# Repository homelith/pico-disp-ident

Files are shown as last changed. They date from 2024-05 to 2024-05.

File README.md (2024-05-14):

# pico-disp-ident

## これは何？

- RP2040 搭載ボードと PicoDVI (https://github.com/Wren6991/PicoDVI) を使って、DVI ディスプレイに番号入りのテストパターン表示をさせるツールです。
- PicoDVI の feat/x8scale ブランチ (https://github.com/homelith/PicoDVI/tree/feat/x8scale) 版を用いることで、80x60 画像を VGA 640x480 ディスプレイに引き延ばして表示します。

## ハードウェア構築

- 記載中

## ソフトウェアビルド

- 環境準備
  + Linux ベースの OS 各種上でコンパイル可能と想定 (x86_64 ネイティブの ubuntu 22.04 LTS と WSL2 上の ubuntu 22.04 LTS で試験済)
  + パッケージインストール : `sudo apt install git gcc make cmake gcc-arm-none-eabi libnewlib-arm-none-eabi build-essential golang`

- uf2 バイナリをコンパイルする手順
  + 下記手順でコンパイル後、`sw/build/app/pico-disp-ident.uf2` が得られます

```
$ git clone --recursive git@github.com:homelith/pico-disp-ident.git
$ cd pico-disp-ident/sw
$ make
```

## デバイスを動作させる手順

- Raspberry Pi Pico への uf2 ファイルダウンロード
  + BOOTSEL ボタンを押しながら Raspi Pico の電源を投入することで、USB ポートがマスストレージデバイスとして認識されます
  + `pico-disp-ident.uf2` ファイルを該当ストレージの直下に置くことで書き込みとセルフリセットが行われます

- ボタンを押下すると表示画像と対応する 7seg の表示番号が切り替わります

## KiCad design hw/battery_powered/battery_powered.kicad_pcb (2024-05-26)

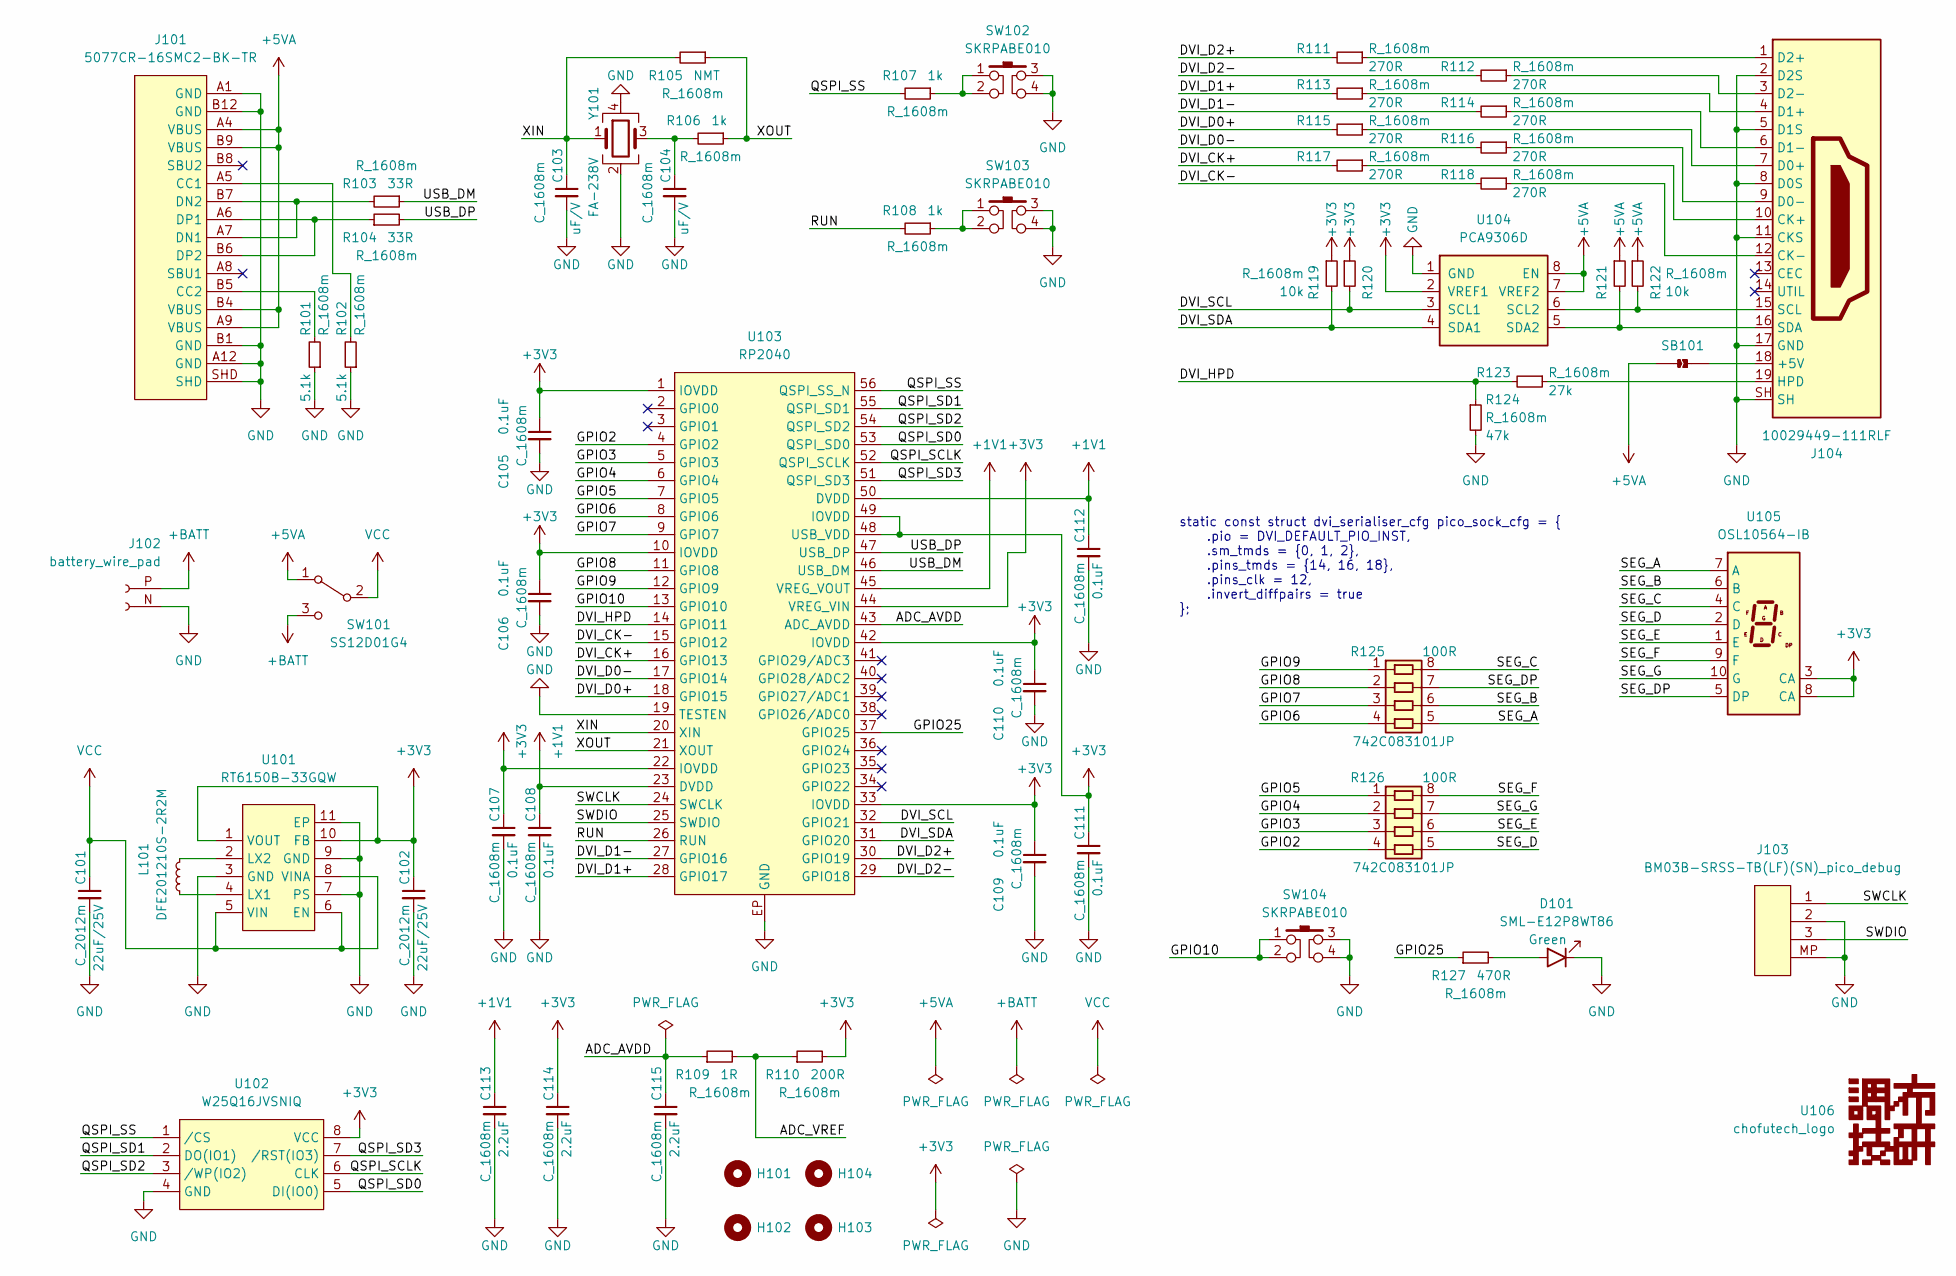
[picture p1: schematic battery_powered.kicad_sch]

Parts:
C101, C102: C_2012m
C103, C104, C105, C106, C107, C108, C109, C110, C111, C112, C113, C114, C115: C_1608m
D101: SML-E12P8WT86
H101, H102, H103, H104: MountingHole_2.2mm_M2; MountingHole_3.2mm_M3
J101: 5077CR-16SMC2-BK-TR; 5077CR-16SMC2-BK-TR_hand
J102: battery_wire_pad
J103: BM03B-SRSS-TB(LF)(SN)_pico_debug; BM03B-SRSS-TB(LF)(SN)_hand
J104: 10029449-111RLF; 10029449-111RLF_hand
L101: DFE201210S-2R2M
R101, R102, R103, R104, R105, R106, R107, R108, R109, R110, R111, R112, R113, R114, R115, R116, R117, R118, R119, R120, R121, R122, R123, R124, R127: R_1608m
R125, R126: 742C083101JP
SB101: jumper_2pole_solder
SW101: SS12D01G4
SW102, SW103, SW104: SKRPABE010; SKRPABE010_hand
U101: RT6150B-33GQW
U102: W25Q16JVSNIQ
U103: RP2040
U104: PCA9306D
U105: OSL10564-IB
U106: chofutech_logo; chofutech_logo_6.6mm
Y101: FA-238V

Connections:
+1V1: C108.1, C112.1, C113.1, U103.23 (DVDD), U103.45 (VREG_VOUT), U103.50 (DVDD)
+3V3: C102.1, C105.1, C106.1, C107.1, C109.1, C110.1, C111.1, C114.1, R110.2, R119.1, R120.1, U101.1 (VOUT), U101.10 (FB), U102.8 (VCC), U103.1 (IOVDD), U103.10 (IOVDD), U103.22 (IOVDD), U103.33 (IOVDD), U103.42 (IOVDD), U103.44 (VREG_VIN), U103.48 (USB_VDD), U103.49 (IOVDD), U104.2 (VREF1), U105.3 (CA), U105.8 (CA)
+5VA: J101.A4 (VBUS), J101.A9 (VBUS), J101.B4 (VBUS), J101.B9 (VBUS), R121.1, R122.1, SB101.1 (A), SW101.1 (A), U104.7 (VREF2), U104.8 (EN)
+BATT: J102.P (Pin_1), SW101.3 (C)
/ADC_AVDD: C115.1, R109.1, U103.43 (ADC_AVDD)
/ADC_VREF: R109.2, R110.1
/DVI_CK+: R117.2, U103.16 (GPIO13)
/DVI_CK-: R118.2, U103.15 (GPIO12)
/DVI_D0+: R115.2, U103.18 (GPIO15)
/DVI_D0-: R116.2, U103.17 (GPIO14)
/DVI_D1+: R113.2, U103.28 (GPIO17)
/DVI_D1-: R114.2, U103.27 (GPIO16)
/DVI_D2+: R111.2, U103.30 (GPIO19)
/DVI_D2-: R112.2, U103.29 (GPIO18)
/DVI_HPD: R123.2, R124.1, U103.14 (GPIO11)
/DVI_SCL: R120.2, U103.32 (GPIO21), U104.3 (SCL1)
/DVI_SDA: R119.2, U103.31 (GPIO20), U104.4 (SDA1)
/GPIO2: R126.4, U103.4 (GPIO2)
/GPIO3: R126.3, U103.5 (GPIO3)
/GPIO4: R126.2, U103.6 (GPIO4)
/GPIO5: R126.1, U103.7 (GPIO5)
/GPIO6: R125.4, U103.8 (GPIO6)
/GPIO7: R125.3, U103.9 (GPIO7)
/GPIO8: R125.2, U103.11 (GPIO8)
/GPIO9: R125.1, U103.12 (GPIO9)
/GPIO10: SW104.1, SW104.2, U103.13 (GPIO10)
/GPIO25: R127.1, U103.37 (GPIO25)
/QSPI_SCLK: U102.6 (CLK), U103.52 (QSPI_SCLK)
/QSPI_SD0: U102.5 (DI(IO0)), U103.53 (QSPI_SD0)
/QSPI_SD1: U102.2 (DO(IO1)), U103.55 (QSPI_SD1)
/QSPI_SD2: U102.3 (/WP(IO2)), U103.54 (QSPI_SD2)
/QSPI_SD3: U102.7 (/RST(IO3)), U103.51 (QSPI_SD3)
/QSPI_SS: R107.2, U102.1 (/CS), U103.56 (QSPI_SS_N)
/RUN: R108.2, U103.26 (RUN)
/SEG_A: R125.5, U105.7 (A)
/SEG_B: R125.6, U105.6 (B)
/SEG_C: R125.8, U105.4 (C)
/SEG_D: R126.5, U105.2 (D)
/SEG_DP: R125.7, U105.5 (DP)
/SEG_E: R126.6, U105.1 (E)
/SEG_F: R126.8, U105.9 (F)
/SEG_G: R126.7, U105.10 (G)
/SWCLK: J103.1, U103.24 (SWCLK)
/SWDIO: J103.3, U103.25 (SWDIO)
/USB_DM: R103.1, U103.46 (USB_DM)
/USB_DP: R104.2, U103.47 (USB_DP)
/XIN: C103.1, R105.2, U103.20 (XIN), Y101.1
/XOUT: R105.1, R106.1, U103.21 (XOUT)
GND: C101.2, C102.2, C103.2, C104.2, C105.2, C106.2, C107.2, C108.2, C109.2, C110.2, C111.2, C112.2, C113.2, C114.2, C115.2, D101.1 (K), J101.A1 (GND), J101.A12 (GND), J101.B1 (GND), J101.B12 (GND), J101.SHD, J102.N (Pin_2), J103.2, J103.MP, J104.2 (D2S), J104.5 (D1S), J104.8 (D0S), J104.11 (CKS), J104.17 (GND), J104.SH, R101.1, R102.1, R124.2, SW102.3, SW102.4, SW103.3, SW103.4, SW104.3, SW104.4, U101.3 (GND), U101.7 (PS), U101.9 (GND), U101.11 (EP), U102.4 (GND), U103.19 (TESTEN), U103.EP (GND), U104.1 (GND), Y101.2, Y101.4
unnamed: C104.1, R106.2, Y101.3
unnamed: D101.2 (A), R127.2
unnamed: J101.A5 (CC1), R102.2
unnamed: J101.A6 (DP1), J101.B6 (DP2), R104.1
unnamed: J101.A7 (DN1), J101.B7 (DN2), R103.2
unnamed: J101.B5 (CC2), R101.2
unnamed: J104.1 (D2+), R111.1
unnamed: J104.3 (D2-), R112.1
unnamed: J104.4 (D1+), R113.1
unnamed: J104.6 (D1-), R114.1
unnamed: J104.7 (D0+), R115.1
unnamed: J104.9 (D0-), R116.1
unnamed: J104.10 (CK+), R117.1
unnamed: J104.12 (CK-), R118.1
unnamed: J104.15 (SCL), R122.2, U104.6 (SCL2)
unnamed: J104.16 (SDA), R121.2, U104.5 (SDA2)
unnamed: J104.18 (+5V), SB101.2 (B)
unnamed: J104.19 (HPD), R123.1
unnamed: L101.1, U101.2 (LX2)
unnamed: L101.2, U101.4 (LX1)
unnamed: R107.1, SW102.1, SW102.2
unnamed: R108.1, SW103.1, SW103.2
VCC: C101.1, SW101.2 (B), U101.5 (VIN), U101.6 (EN), U101.8 (VINA)

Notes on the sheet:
static const struct dvi_serialiser_cfg pico_sock_cfg = { .pio = DVI_DEFAULT_PIO_INST, .sm_tmds = {0, 1, 2}, .pins_tmds = {14, 16, 18}, .pins_clk = 12, .invert_diffpairs = true };

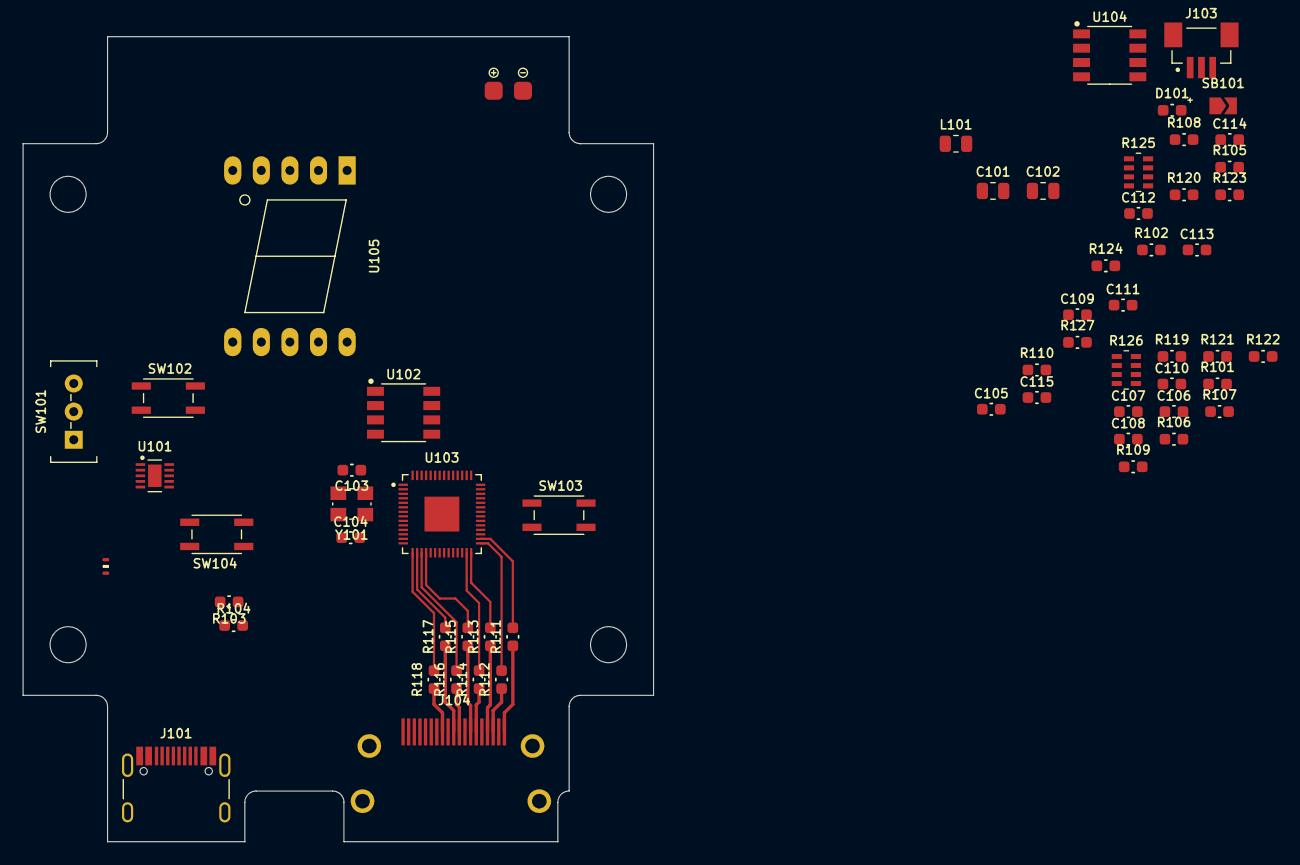
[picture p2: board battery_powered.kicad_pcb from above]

Board: 4 copper layers, 56.0 x 71.5 mm, 64 parts (0 on the bottom side), 72 nets.

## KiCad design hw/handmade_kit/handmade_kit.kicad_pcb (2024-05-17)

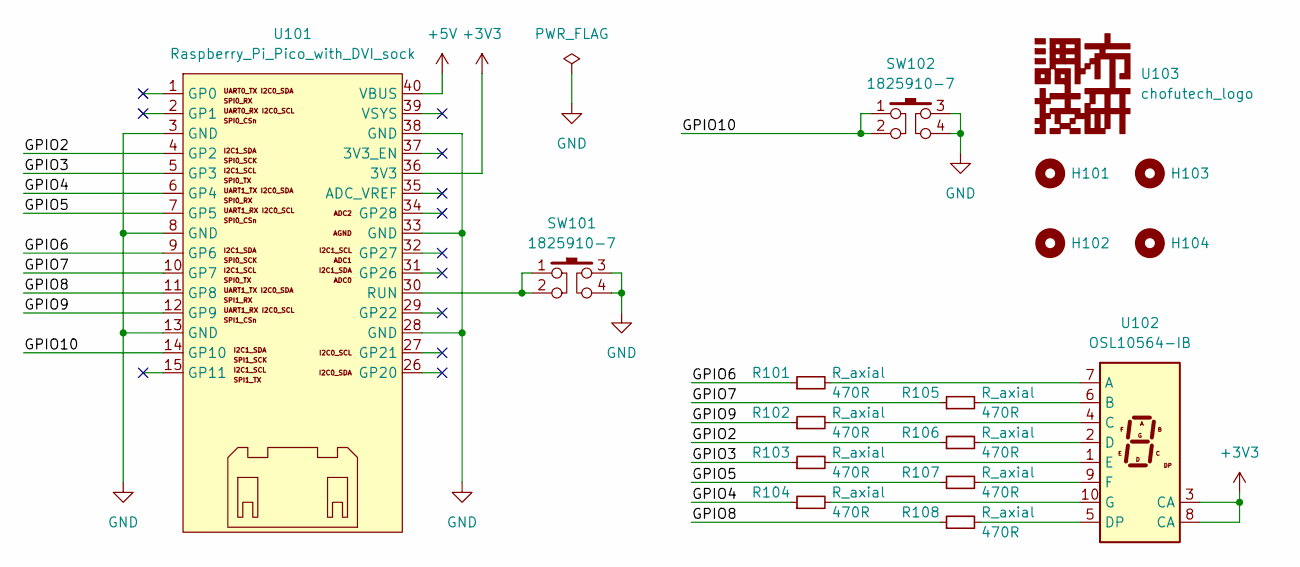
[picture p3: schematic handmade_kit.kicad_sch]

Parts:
H101, H102, H103, H104: MountingHole_2.2mm_M2
R101, R102, R103, R104, R105, R106, R107, R108: R_axial
SW101, SW102: 1825910-7
U101: Raspberry_Pi_Pico_with_DVI_sock
U102: OSL10564-IB
U103: chofutech_logo; chofutech_logo_6.6mm

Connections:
+3V3: U101.36 (3V3), U102.3 (CA), U102.8 (CA)
+5V: U101.40 (VBUS)
/GPIO2: R106.1, U101.4 (GP2)
/GPIO3: R103.1, U101.5 (GP3)
/GPIO4: R104.1, U101.6 (GP4)
/GPIO5: R107.1, U101.7 (GP5)
/GPIO6: R101.1, U101.9 (GP6)
/GPIO7: R105.1, U101.10 (GP7)
/GPIO8: R108.1, U101.11 (GP8)
/GPIO9: R102.1, U101.12 (GP9)
/GPIO10: SW102.1, SW102.2, U101.14 (GP10)
GND: SW101.3, SW101.4, SW102.3, SW102.4, U101.3 (GND), U101.8 (GND), U101.13 (GND), U101.28 (GND), U101.33 (GND), U101.38 (GND)
unnamed: R101.2, U102.7 (A)
unnamed: R102.2, U102.4 (C)
unnamed: R103.2, U102.1 (E)
unnamed: R104.2, U102.10 (G)
unnamed: R105.2, U102.6 (B)
unnamed: R106.2, U102.2 (D)
unnamed: R107.2, U102.9 (F)
unnamed: R108.2, U102.5 (DP)
unnamed: SW101.1, SW101.2, U101.30 (RUN)

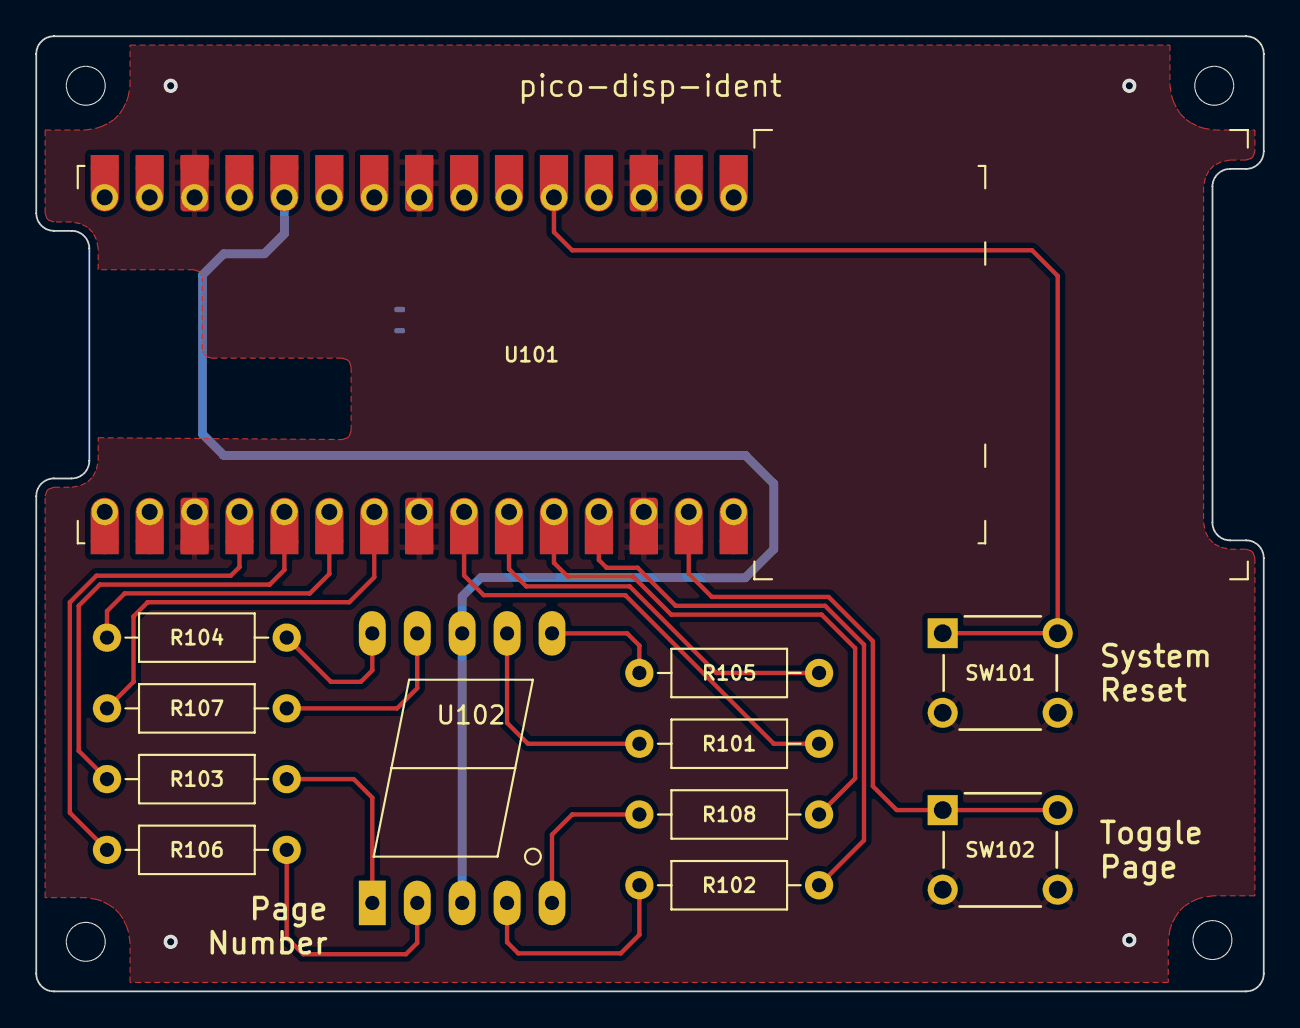
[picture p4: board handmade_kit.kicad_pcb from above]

Board: 2 copper layers, 69.4 x 54.0 mm, 17 parts (1 on the bottom side), 20 nets.

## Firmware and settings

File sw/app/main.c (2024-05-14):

//------------------------------------------------------------------------------
// main.c
//------------------------------------------------------------------------------

//------------------------------------------------------------------------------
// MIT License
//
// Copyright (c) 2022 homelith
//
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
#include <stdio.h>
#include <stdlib.h>

#include "boards/pico.h"
#include "pico/stdlib.h"
#include "pico/multicore.h"
#include "pico/binary_info.h"
#include "hardware/clocks.h"
#include "hardware/irq.h"
#include "hardware/sync.h"
#include "hardware/gpio.h"
#include "hardware/uart.h"
#include "hardware/vreg.h"
#include "dvi.h"
#include "dvi_serialiser.h"
#include "common_dvi_pin_configs.h"

#include "cb.h"

#define VREG_VSEL VREG_VOLTAGE_1_20
#define DVI_TIMING dvi_timing_640x480p_60hz

#define FRAME_WIDTH             80
#define FRAME_HEIGHT            60
#define PAGE_NUM                10

#define UART0_TX_QUEUE_SIZE     1024

#define PIN_LED                 25
#define PIN_7SEG_A              6
#define PIN_7SEG_B              7
#define PIN_7SEG_C              9
#define PIN_7SEG_D              2
#define PIN_7SEG_E              3
#define PIN_7SEG_F              5
#define PIN_7SEG_G              4
#define PIN_7SEG_DP             8
#define PIN_PSW                 10

typedef struct QUEUE_tag{
	uint8_t *buf;
	uint16_t head;
	uint16_t tail;
	uint16_t size;
} QUEUE;

struct dvi_inst dvi0;
uint8_t uart0_tx_queue_buf[UART0_TX_QUEUE_SIZE];

bool queue_push(QUEUE *q, uint8_t data) {
	uint16_t next_head = (q->head == q->size - 1) ? 0 : q->head + 1;
	if (next_head != q->tail) {
		q->buf[q->head] = data;
		q->head = next_head;
		return true;
	} else {
		return false;
	}
}
bool queue_pop(QUEUE *q, uint8_t *data) {
	if (q->head != q->tail) {
		(*data) = q->buf[q->tail];
		q->tail = (q->tail == q->size - 1) ? 0 : q->tail + 1;
		return true;
	} else {
		(*data) = 0;
		return false;
	}
}
uint8_t queue_puts(QUEUE *q, uint8_t *str, uint16_t num, bool stop_on_null) {
	for (uint8_t i = 0; i < num; i ++) {
		if (stop_on_null && str[i] == '\0') {
			return i;
		}
		if (! queue_push(q, str[i])) {
			return i;
		}
	}
	return num;
}

uint8_t hex2char(uint8_t h) {
	if (h < 10) {
		return (uint8_t)(h + 48);
	} else if (h < 16) {
		return (uint8_t)(h + 87);
	} else {
		return '*';
	}
}
uint8_t char2hex(uint8_t c) {
	if (c < 48) {
		return 0;
	} else if (c < 58) {
		return (uint8_t)(c - 48);
	} else if (c < 65) {
		return 0;
	} else if (c < 71) {
		return (uint8_t)(c - 55);
	} else if (c < 97) {
		return 0;
	} else if (c < 103) {
		return (uint8_t)(c - 87);
	} else {
		return 0;
	}
}

void set_7seg(uint8_t num) {
	uint8_t digit;
	switch(num) {
		case  0: digit = 0xC0; break;
		case  1: digit = 0xF9; break;
		case  2: digit = 0xA4; break;
		case  3: digit = 0xB0; break;
		case  4: digit = 0x99; break;
		case  5: digit = 0x92; break;
		case  6: digit = 0x82; break;
		case  7: digit = 0xD8; break;
		case  8: digit = 0x80; break;
		case  9: digit = 0x90; break;
		default: digit = 0xFF; break;
	}
	gpio_put(PIN_7SEG_A, (bool)(digit & 0x01)); digit = digit >> 1;
	gpio_put(PIN_7SEG_B, (bool)(digit & 0x01)); digit = digit >> 1;
	gpio_put(PIN_7SEG_C, (bool)(digit & 0x01)); digit = digit >> 1;
	gpio_put(PIN_7SEG_D, (bool)(digit & 0x01)); digit = digit >> 1;
	gpio_put(PIN_7SEG_E, (bool)(digit & 0x01)); digit = digit >> 1;
	gpio_put(PIN_7SEG_F, (bool)(digit & 0x01)); digit = digit >> 1;
	gpio_put(PIN_7SEG_G, (bool)(digit & 0x01)); digit = digit >> 1;
	gpio_put(PIN_7SEG_DP, (bool)(digit & 0x01)); digit = digit >> 1;
}

void core1_main() {
	// core1 extracts pixel data from 'CPU0 -> CPU1' FIFO, encode it to tmds symbol,
	// and push tmds symbol to 'CPU1 -> PIO' FIFO
	dvi_register_irqs_this_core(&dvi0, DMA_IRQ_0);
	while (queue_is_empty(&dvi0.q_colour_valid))
		__wfe();
	dvi_start(&dvi0);
	dvi_scanbuf_x8scale_main_16bpp(&dvi0);
}


int main() {
	// queues
	QUEUE uart0_tx_queue;
	uart0_tx_queue.buf  = uart0_tx_queue_buf;
	uart0_tx_queue.head = 0;
	uart0_tx_queue.tail = 0;
	uart0_tx_queue.size = UART0_TX_QUEUE_SIZE;

	// switch controls
	bool     sw_delayline[3] = {false, false, false};
	bool     sw = false;
	bool     sw_prev = false;
	bool     sw_rise = false;
	uint64_t sw_prev_tick = 0;

	// dvi controls
	uint16_t dvi_line_idx = 0;
	uint16_t dvi_page_idx = 0;

	// system global setting
	vreg_set_voltage(VREG_VSEL);
	sleep_ms(10);
	set_sys_clock_khz(DVI_TIMING.bit_clk_khz, true);

	// setup LED and push button
	gpio_init(PIN_LED);
	gpio_set_dir(PIN_LED, GPIO_OUT);
	gpio_init(PIN_7SEG_A);
	gpio_init(PIN_7SEG_B);
	gpio_init(PIN_7SEG_C);
	gpio_init(PIN_7SEG_D);
	gpio_init(PIN_7SEG_E);
	gpio_init(PIN_7SEG_F);
	gpio_init(PIN_7SEG_G);
	gpio_init(PIN_7SEG_DP);
	gpio_set_dir(PIN_7SEG_A, GPIO_OUT);
	gpio_set_dir(PIN_7SEG_B, GPIO_OUT);
	gpio_set_dir(PIN_7SEG_C, GPIO_OUT);
	gpio_set_dir(PIN_7SEG_D, GPIO_OUT);
	gpio_set_dir(PIN_7SEG_E, GPIO_OUT);
	gpio_set_dir(PIN_7SEG_F, GPIO_OUT);
	gpio_set_dir(PIN_7SEG_G, GPIO_OUT);
	gpio_set_dir(PIN_7SEG_DP, GPIO_OUT);
	gpio_init(PIN_PSW);
	gpio_set_dir(PIN_PSW, GPIO_IN);
	gpio_pull_up(PIN_PSW);

	// set up serials
	stdio_init_all();

	// init bitbang DVI library
	dvi0.timing = &DVI_TIMING;
	dvi0.ser_cfg = DVI_DEFAULT_SERIAL_CONFIG;
	dvi_init(&dvi0, next_striped_spin_lock_num(), next_striped_spin_lock_num());

	// Core 1 will wait until it sees the first colour buffer, then start up the
	// DVI signalling.
	multicore_launch_core1(core1_main);

	// init 7seg
	gpio_put(PIN_7SEG_A, true);
	gpio_put(PIN_7SEG_B, true);
	gpio_put(PIN_7SEG_C, true);
	gpio_put(PIN_7SEG_D, true);
	gpio_put(PIN_7SEG_E, true);
	gpio_put(PIN_7SEG_F, true);
	gpio_put(PIN_7SEG_G, true);
	gpio_put(PIN_7SEG_DP, true);
	set_7seg((dvi_page_idx + 1) % PAGE_NUM);

	// indicate init completed
	for (uint8_t i = 0; i < 3; i ++) {
		gpio_put(PIN_LED, true);
		sleep_ms(200);
		gpio_put(PIN_LED, false);
		sleep_ms(200);
	}
	queue_puts(&uart0_tx_queue, (uint8_t*)"pico-disp-ident started\r\n", 256, true);

	while (true) {
		uint64_t curr_tick = time_us_64();

		//--------------------------------------------------------------
		// remove sw chattering and detect edge
		// 10ms sampling -> 3 stage consensus -> edge detection
		//--------------------------------------------------------------
		if (curr_tick - sw_prev_tick > 10000) {
			sw_prev_tick = curr_tick;
			sw_delayline[2] = sw_delayline[1];
			sw_delayline[1] = sw_delayline[0];
			sw_delayline[0] = !(gpio_get(PIN_PSW));
			if (sw_delayline[2] & sw_delayline[1] & sw_delayline[0]) {
				sw = true;
			}
			if (!(sw_delayline[2] | sw_delayline[1] | sw_delayline[0])) {
				sw = false;
			}
		}
		if (!(sw_prev) & sw) {
			sw_rise = true;
		} else {
			sw_rise = false;
		}
		sw_prev = sw;

		// increment dvi page
		if (sw_rise) {
			if (dvi_page_idx == PAGE_NUM-1) {
				dvi_page_idx = 0;
			} else {
				dvi_page_idx ++;
			}
			// change 7seg state
			set_7seg((dvi_page_idx + 1) % PAGE_NUM);
		}


		//--------------------------------------------------------------
		// tx queue rate limited flushing
		// (approx. 1 byte per 1 horizontal scan time == 9600 times/s)
		//--------------------------------------------------------------
		// pop from uart0_tx_queue and push to uart0
		if (uart_is_writable(uart0)) {
			uint8_t c;
			if (queue_pop(&uart0_tx_queue, &c)) {
				putchar(c);
			}
		}

		//--------------------------------------------------------------
		// feeding image line to DVI color linebuffer
		//--------------------------------------------------------------
		// push image buf to inter CPU0 -> CPU1 FIFO
		const uint16_t *scanline = &((const uint16_t*)cb)[(dvi_page_idx * FRAME_HEIGHT + dvi_line_idx) * FRAME_WIDTH];
		queue_add_blocking_u32(&dvi0.q_colour_valid, &scanline);
		while (queue_try_remove_u32(&dvi0.q_colour_free, &scanline));

		// increment line index
		if (dvi_line_idx == (FRAME_HEIGHT - 1)) {
			dvi_line_idx = 0;
		} else {
			dvi_line_idx ++;
		}
	}
}

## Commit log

2024-05-17 add handmade_kit pcb design and battery_powered pcb skelton
    [battery_powered.kicad_pcb, battery_powered.kicad_sch, handmade_kit.kicad_pcb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]
2024-05-17 plotted handmade_kit r01
    [handmade_kit.kicad_pcb]
2024-05-17 filled battery_powered schematics
    [battery_powered.kicad_sch]
2024-05-18 add battery_powered footprints
    [battery_powered.kicad_pcb, battery_powered.kicad_sch]
2024-05-22 add DVI output circuit to battery_powered composition
    [battery_powered.kicad_pcb, battery_powered.kicad_sch]
2024-05-23 change DVI pin assignment (PicoDVI cfg written in schematic)
    [battery_powered.kicad_pcb, battery_powered.kicad_sch]
2024-05-26 fixed battery_powered artwork and add .gitkeep to build dir
    [battery_powered.kicad_pcb]
